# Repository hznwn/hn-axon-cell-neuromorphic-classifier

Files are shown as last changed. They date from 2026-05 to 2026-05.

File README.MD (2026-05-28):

# HN Axon Cell Neuromorphic Classifier

Discrete hardware implementation of the HN Axon Cell, a biologically inspired integrate-and-fire neuron for real-time light-direction classification using a 3×3 LDR sensor array, current mirrors, LTspice simulations, Arduino code, CAD models, and experimental data.

---
## Thesis Poster
<p align="center">
  <a href="media/HN_PRINT_A0.jpg">
    
  </a>
</p>

## Overview

This repository contains all source files, simulation models, experimental data, CAD designs, supplementary materials, and documentation associated with the bachelor's thesis:

**Implementation and Characterisation of a Discrete Neuromorphic Hardware System for Real-Time Light-Direction Classification**

The project investigates how core principles of biological neurons can be implemented using discrete electronic components. The resulting system, referred to as the **HN Axon Cell (HNAC)**, performs temporal integration, threshold detection, spike generation, and membrane reset to produce spike-frequency encoded outputs.

Nine HN Axon Cells were integrated with a curved 3×3 array of light-dependent resistors (LDRs) and an Arduino Uno R4 WiFi to create a complete neuromorphic system capable of real-time light-direction classification.

The prototype includes:

- 9 discrete integrate-and-fire neurons
- 9 light-dependent resistors (LDRs) arranged in a 3×3 sensor array
- CD4051B analogue multiplexer
- Arduino Uno R4 WiFi
- Automatic self-calibration and supervised template learning
- Real-time direction classification
- USB-C power consumption below 1 W

---

## Key Features

- Discrete implementation of an integrate-and-fire neuron
- Current mirror-based input stage
- Spike-frequency encoding of analogue sensor signals
- Real-time classification of light direction using a 3×3 LDR array
- Arduino-based template matching and LED matrix visualization
- LTspice simulation models
- Oscilloscope screenshots and experimental data
- 3D-printable sensor enclosure
- Full thesis documentation and supplementary materials

---

## Biological Inspiration

The HN Axon Cell is based on the leaky integrate-and-fire (LIF) neuron model.

| Biological Concept | Hardware Implementation |
|---|---|
| Membrane | Capacitor |
| Synaptic input current | PMOS current mirror |
| Threshold detection | SN74AHC14 Schmitt trigger |
| Spike and reset | BS170 MOSFET |
| Refractory shaping | Optional feedback capacitor |

---

## Repository Structure

```text
hn-axon-cell-neuromorphic-classifier/
├── arduino/
│   └── hn_axon_cell_classifier.ino
├── ltspice/
│   ├── preliminary_architectures/
│   ├── architecture_1/
│   └── hn_axon_cell/
├── cad/
│   └── ldr_sensor_array_3x3_curved.f3d
├── data/
│   ├── raw_measurements/
│   ├── calibration_templates/
│   ├── processed_results/
│   └── FINALRESULTS.csv
├── figures/
│   ├── oscilloscope/
│   ├── circuit_photos/
│   └── classification_demo/
├── docs/
│   ├── laboratory_notes/
│   │   └── HN_Axon_Cell_Laboratory_Development_Notes.pdf
│   ├── supplementary_material/
│   └── media/
├── thesis/
│   └── Thesis.pdf
├── LICENSE
└── README.md

⸻

Hardware Components
Neuron Circuit
	•	SN74AHC14 Schmitt trigger inverter
	•	BS170 NMOS transistor
	•	BS250 PMOS transistors
	•	Capacitors and resistors
	•	Light-dependent resistors (LDRs)
System Components
	•	Arduino Uno R4 WiFi
	•	CD4051B analogue multiplexer
	•	3×3 curved LDR sensor array
	•	USB 5 V power supply

⸻

Experimental Results
The HN Axon Cell exhibited:
	•	Stable and repeatable integrate-and-fire oscillations
	•	Firing frequency inversely proportional to membrane capacitance
	•	Stable threshold voltages across parameter sweeps
	•	Successful conversion of light intensity into spike frequency
	•	Reliable real-time classification of flashlight position
The completed system consistently identified the illuminated sensor position and displayed the detected direction on the Arduino LED matrix.

⸻

Supplementary Materials

The repository includes extensive supplementary material documenting the complete system and experimental results.
Supplementary Videos
Supplementary_Video_S1_Complete_System_Startup_Self_Training_and_Real_Time_3x3_Neuromorphic_Classification.MOV

Complete end-to-end demonstration showing:
	•	Program startup
	•	Ambient baseline calibration
	•	Self-training on all nine sensor positions
	•	Transition to live mode
	•	Real-time direction classification
Supplementary_Video_S4_Random_Order_3x3_Neuromorphic_Classification_Accuracy_Demonstration.MOV
Demonstrates classification of all nine sensor positions in random order. All positions were classified correctly during the recorded test.

⸻

Representative Neuron Oscilloscope Captures:
Oscilloscope_20260513_004451_Neuron7_IntegrateAndFire_Covered_LDR_Input_USB_C_Powered_5V.jpeg
Neuron 7 response with the corresponding LDR covered (minimal illumination).
Oscilloscope_20260513_004514_Neuron7_IntegrateAndFire_Ambient_Light_LDR_Input_USB_C_Powered_5V.jpeg
Neuron 7 response under ambient room lighting.
Oscilloscope_20260513_004541_Neuron7_IntegrateAndFire_Direct_Flashlight_LDR_Input_USB_C_Powered_5V.jpeg
Neuron 7 response under direct flashlight illumination.
These three captures demonstrate spike-frequency encoding, where the firing rate increases with increasing light intensity.

⸻

System Figures:
3x3_LDR_Sensor_Array_and_Neuromorphic_Neuron_Mapping.png
Physical layout and channel mapping of the 3×3 LDR sensor array.
Self_Training_3x3_Neuromorphic_Classification_System_Idle_Four_Corner_LEDs_USB_C_Powered_5V.png
Idle state of the classifier when no significant light stimulus is detected.
Self_Training_3x3_Neuromorphic_Classification_System_Active_Direction_Detection_USB_C_Powered_5V.png
Example of active real-time direction classification.
System_Power_Measurement_5p158V_0p154A_0p789W_USB_C_Powered.png
USB power measurement of the complete prototype.

⸻

Hardware Photographs:
	•	Neuron1-4.HEIC
Photograph of neurons 1 through 4.
	•	Neuron1-4_with_3dprint_plus_LDRs3x3.HEIC
Neurons 1 through 4 together with the 3D-printed sensor array.
	•	Neuron4_close_up.HEIC
Close-up photograph of a representative neuron.
	•	Neuron5-9_plus_meter_plus_arduino_plus_multiplexer.HEIC
Neurons 5 through 9 together with the Arduino, multiplexer, and power meter.
	•	Neuron5-9_plus_meter_plus_arduino_plus_multiplexer_plus_back_3x3LDR_3dprint.HEIC
Comprehensive overview of the complete hardware prototype.
	•	Neuron7-9.HEIC
Photograph of neurons 7 through 9.

⸻

Data Files:
FINALRESULTS.csv
Final validated dataset collected on May 13, 2026.
Contains sensor readings and classification outputs from the completed self-training 3×3 neuromorphic classification system after all hardware and software optimizations were finalized.

⸻

Power Consumption:
Measured using a KWS-2302C USB power meter.
Parameter
Value
Voltage
5.158 V
Current
0.154 A
Power
0.789 W
Estimated meter overhead: approximately 0.01 to 0.05 W.
Estimated actual system power consumption: approximately 0.74 to 0.78 W.
These measurements confirm that the complete neuromorphic classification system operates well below 1 W.

⸻

System Notes
	•	The system performs self-calibration and retraining at every startup.
	•	The classifier adapts to different ambient lighting conditions.
	•	Sensors N1 to N8 are read through the CD4051B analogue multiplexer.
	•	Sensor N9 is connected directly to Arduino analogue input A1.
	•	The system is powered entirely from a standard 5 V USB-C connection.

⸻

Thesis Abstract
This work demonstrates how biologically inspired neural computation can be implemented using discrete electronic components. The developed HN Axon Cell reproduces the core behaviour of a spiking neuron and forms the basis of a nine-neuron neuromorphic hardware system capable of real-time light-direction classification.
The project bridges theoretical neuroscience, analogue circuit design, simulation, embedded programming, and experimental validation.

⸻

Software and Tools Used
	•	LTspice
	•	Arduino IDE
	•	Microsoft Word
	•	Fusion 360
	•	Rigol DS1202 Oscilloscope

⸻

License
This project is licensed under the MIT License. See the LICENSE file for details.

⸻

Author
Haze Newman
Bachelor’s Thesis in Electrical Engineering
Uppsala University
2026

⸻

Citation
If you use this work in research or development, please cite the associated bachelor’s thesis and reference this repository.

⸻

Contact
For questions, collaboration, or future research opportunities, please open an issue on GitHub.

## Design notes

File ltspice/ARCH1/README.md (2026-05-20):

ARCH1_SIMULATION_ONLY
=====================

Description
-----------
This LTspice file contains a functional simulation of the preliminary voltage-driven integrate-and-fire neuron developed during the early stages of this thesis project.

The circuit served as the first proof-of-concept implementation and was used to verify that a discrete electronic circuit could reproduce the essential behaviour of a biological spiking neuron.

Important Note
--------------
This simulation file is intended for functional validation only and does NOT necessarily represent the exact component values used in the final experimental implementation.

Several component values were adjusted to obtain stable and visually clear integrate-and-fire behaviour in LTspice. The simulation should therefore be interpreted as a conceptual demonstration rather than an exact replication of the physical prototype.

The corresponding file ARCH1_SCHEMATIC_ONLY contains a clean schematic of the architecture and includes both the fixed resistive input and the optional LDR-based voltage divider used in early experiments.

Purpose of the Simulation
-------------------------
The simulation was created to verify the following sequence of operations:

1. The membrane capacitor is charged through a resistive input stage.
2. The membrane voltage (Vmem) increases over time.
3. A Schmitt trigger detects when the threshold is reached.
4. A second inverter restores the correct signal polarity.
5. An NMOS transistor rapidly discharges the membrane capacitor.
6. The cycle repeats, producing integrate-and-fire oscillations.

This behaviour reproduces the fundamental principles of the leaky integrate-and-fire neuron model.

Architecture Overview
---------------------
The preliminary architecture consists of:

- Input resistor or LDR-based voltage divider
- Membrane capacitor (Cmem)
- Two SN74AHC14 Schmitt-trigger inverter stages
- BS170 NMOS reset transistor
- Supporting resistors

The same threshold and reset subsystem was later reused in the HN Axon Cell, where the resistive input stage was replaced by a PMOS current mirror.

Simulation Files
----------------
ARCH1_SCHEMATIC_ONLY.asc
    Clean schematic of the preliminary voltage-driven architecture.

ARCH1_SIMULATION_ONLY.asc
    Functional LTspice simulation used to demonstrate integrate-and-fire behaviour.

README.txt
    This document.

Models Used
-----------
- SN74AHC14.cir
- BS170 model defined directly in the schematic

Interpretation of Results
-------------------------
The most important output is the membrane voltage Vmem.

A successful simulation produces a sawtooth waveform showing:

- gradual charging of the membrane capacitor,
- threshold crossing,
- rapid reset,
- repeated oscillation.

The output of the Schmitt trigger stages appears as a digital spike train.

Relationship to the HN Axon Cell
--------------------------------
This preliminary architecture was used to validate the fundamental integrate-and-fire mechanism and to perform early experiments with push-button and photoresistor inputs.

After successful testing, the resistive input stage was replaced by a PMOS current mirror, resulting in the HN Axon Cell (HNAC), the final neuron architecture presented in this thesis.

Author
------
Haze Newman
Bachelor's Thesis in Electrical Engineering
Uppsala University
2026

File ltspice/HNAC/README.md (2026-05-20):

HNAC_SIMULATION_ONLY
====================

Description
-----------
This LTspice file contains a functional simulation of the HN Axon Cell (HNAC), a discrete-component neuromorphic neuron developed as part of a Bachelor's thesis in Electrical Engineering at Uppsala University.

The purpose of this simulation is to demonstrate the fundamental integrate-and-fire behaviour of the architecture in a clear and reproducible manner.

Important Note
--------------
This simulation file does NOT represent the exact component values used in the final breadboard implementation.

Several component values were intentionally adjusted to obtain stable and visually clear integrate-and-fire behaviour in LTspice. These modifications were made solely for simulation and demonstration purposes.

The separate file HNAC_SCHEMATIC_ONLY contains the circuit topology and nominal component values corresponding more closely to the physical implementation.

Purpose of the Simulation
-------------------------
The simulation was created to verify the following sequence of operations:

1. Input current charges the membrane capacitor (Cmem).
2. The membrane voltage (Vmem) increases over time.
3. A Schmitt trigger detects when the threshold is reached.
4. A second inverter restores the correct signal polarity.
5. An NMOS transistor rapidly discharges the membrane capacitor.
6. The cycle repeats, producing integrate-and-fire oscillations.

This behaviour reproduces the core computational principles of the leaky integrate-and-fire neuron model.

Simulation-Specific Modifications
---------------------------------
The following adjustments may differ from the final hardware implementation:

- Current mirror bias resistors were tuned to provide sufficient charging current.
- Additional resistors were modified to improve convergence and stability.
- Simulation models were used for:
  - BS250 PMOS transistors
  - BS170 NMOS transistor
  - SN74AHC14 Schmitt trigger inverter
- Initial conditions were specified to ensure proper startup.
- Transient analysis settings were selected to clearly display repetitive firing.

These changes were made to validate the architecture rather than to exactly replicate measured experimental values.

Files Included
--------------
HNAC_SIMULATION_ONLY.asc
    LTspice simulation file with adjusted values for functional validation.

HNAC_SCHEMATIC_ONLY.asc
    Clean schematic showing the architecture and nominal hardware values.

README.txt
    This document.

Models Used
-----------
- BS250.philips.lib
- SN74AHC14.cir
- BS170 model defined directly in the schematic

Interpretation of Results
-------------------------
The most important output is the membrane voltage Vmem.

A successful simulation produces a sawtooth waveform:
- gradual charging of the membrane capacitor,
- threshold crossing,
- rapid reset,
- repeated oscillation.

This confirms correct integrate-and-fire behaviour.

Thesis Context
--------------
This simulation supports the statement that the HN Axon Cell architecture is capable of reproducing biologically inspired spiking neuron dynamics using discrete commercially available electronic components.

The simulation should be interpreted as a functional validation of the design rather than an exact digital twin of the physical breadboard implementation.

Author
------
Haze
Bachelor's Thesis in Electrical Engineering
Uppsala University
2026

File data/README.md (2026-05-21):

README.txt
==========

3×3 Neuromorphic Light-Direction Classification Data and Analysis
=================================================================

This folder contains the raw Arduino IDE serial export and the Python script
used to generate the supplementary classification figures and tables presented
in the appendix of the thesis.

Raw Data File
-------------

Final_Validated_3x3_Neuromorphic_Classification_Results_2026_05_13_arduinoide_export.csv

This file is the original serial data export from the Arduino IDE. It contains:

- Timestamp (time_ms)
- Raw sensor readings (N1–N9)
- Activity metric
- Raw classifier output (rawWinner)
- Stable classifier output (stableWinner)
- Similarity score

The file includes both calibration messages and live classification data.

Python Analysis Script
----------------------

confusion.py

Running this script automatically:

1. Extracts the tabular data from the Arduino IDE export.
2. Detects classification segments using the stable classifier output.
3. Assigns a trueClass label to each segment.
4. Computes classification accuracy.
5. Generates confusion matrices, plots, and summary tables.

Generated Output Files
----------------------

The following files are created in:

generated_classification_figures/

CSV Files
---------

generated_classification_figures/per_class_sample_counts.csv
generated_classification_figures/confusion_matrix_true_vs_predicted.csv
generated_classification_figures/accuracy_by_class.csv
generated_classification_figures/classification_data_with_trueClass.csv
generated_classification_figures/detected_trueclass_time_blocks.csv
generated_classification_figures/similarity_score_summary.csv

Image Files
-----------

generated_classification_figures/classification_stability_over_time.png
generated_classification_figures/confusion_matrix_true_vs_predicted.png
generated_classification_figures/similarity_score_distribution.png
generated_classification_figures/per_class_sample_counts.png
generated_classification_figures/accuracy_by_class.png

Summary of Results
------------------

The analysis produced the following key results:

- 392 valid classification samples
- 100.00% overall classification accuracy
- 100.00% accuracy for all nine classes (N1–N9)
- Zero misclassifications
- Perfect diagonal confusion matrix

These results confirm that the neuromorphic light-direction classification
system operated reliably under the controlled experimental conditions used
in this study.

Requirements
------------

The Python script requires the following packages:

- pandas
- numpy
- matplotlib

Install them using:

pip install pandas numpy matplotlib

Usage
-----

Place the following files in the same directory:

- confusion.py
- Final_Validated_3x3_Neuromorphic_Classification_Results_2026_05_13_arduinoide_export.csv

Run:

python confusion.py

A new folder named generated_classification_figures will be created containing
all generated figures and summary tables.

Author
------

Haza Newman
Uppsala University
Degree Project in Electrical Engineering
2026

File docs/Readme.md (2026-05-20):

Laboratory Development Notes
Supplementary laboratory notes documenting the phases of the project, including circuit development, testing, and experimental observations, are included. These notes are provided in their original handwritten form to preserve the chronological and transparent record of the experimental development of the work:

https://web.goodnotes.com/s/xlsEbIUI6iuXck66CYKlLw

If the Goodnotes link no longer works, the file can be also found via this url (requires UU access):

https://uppsalauniversitet.sharepoint.com/sites/ExperimentDataStorage/Shared%20Documents/Forms/AllItems.aspx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

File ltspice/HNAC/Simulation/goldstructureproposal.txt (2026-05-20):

Intro

The song opens with distant cinematic impacts, reversed cymbals, dark sub drones, and ambient clean guitar swells. Haunting choir pads and soft strings slowly build tension.

Build

Spiccato strings and pizzicato patterns begin to pulse underneath the atmosphere. Timpani rolls and low brass swell as palm-muted Drop A guitars start creeping in.

Verse 1

Crushing Drop A guitars and tight double-kick drums drive the song forward. Symphonic strings mirror the riff while dark synth textures and layered vocals create a massive wall of sound.

Chorus

The energy opens up into a soaring vocal hook supported by harmonized lead guitars, full string ensemble, choir, and emotional chord changes. This is the main melodic centerpiece of the song.

Verse 2

The heavy riff returns with syncopated chugs, aggressive drums, and sharper orchestral accents. Additional vocal layers increase the intensity.

Chorus

The main hook returns with bigger harmonies, denser orchestration, and more emotional weight.

Pre-Breakdown

The arrangement strips back and builds tension with tom fills, rising choirs, tremolo strings, and reversed impacts.

Final Brutal Breakdown

Half-time drums and devastating Drop A guitar accents hit alongside china cymbals, machine-gun kicks, orchestral stabs, and crushing low brass.

Post-Breakdown Resolution

The violence gives way to an epic melodic section where vocals and lead guitars intertwine over soaring strings and powerful half-time drums.

Final Chorus

The largest and most emotional statement of the song. Full choir, brass, dual lead guitars, and layered vocals push the main hook to its peak.

Outro

The arrangement gradually fades with clean guitar echoes, distant choir, sustained strings, and a dark sub drone dissolving into silence.

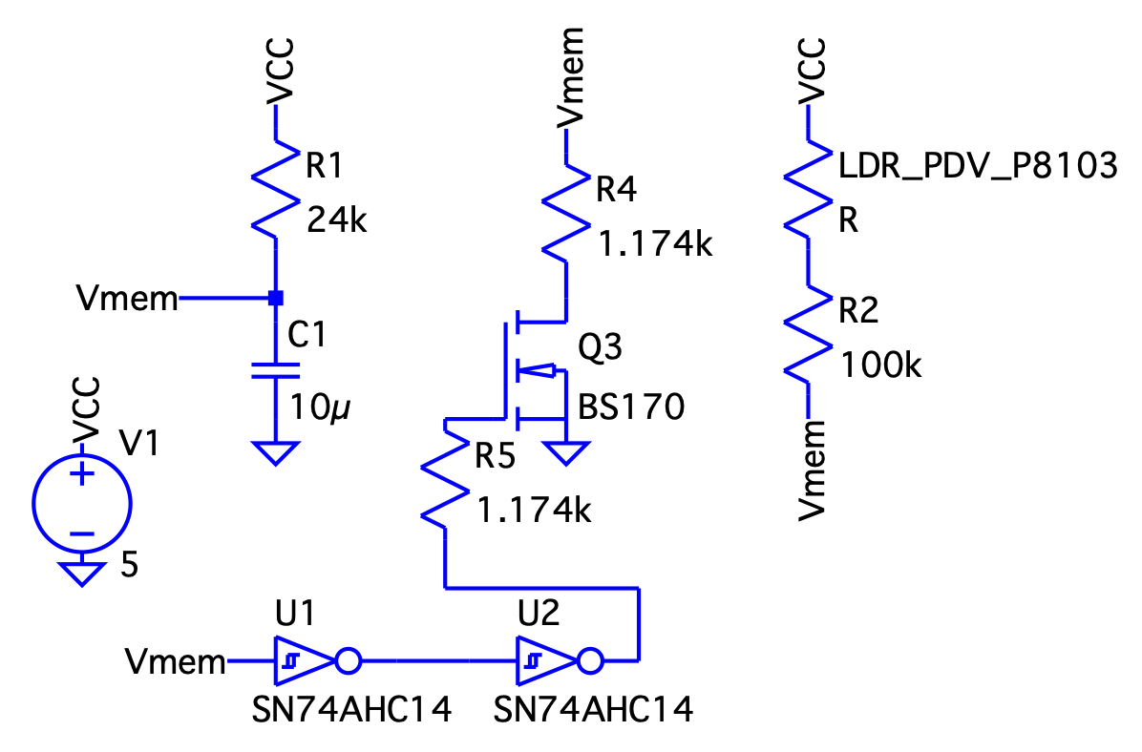
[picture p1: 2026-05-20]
figures/schematics/ARCH1/ARCH1_SCHEMATIC.png

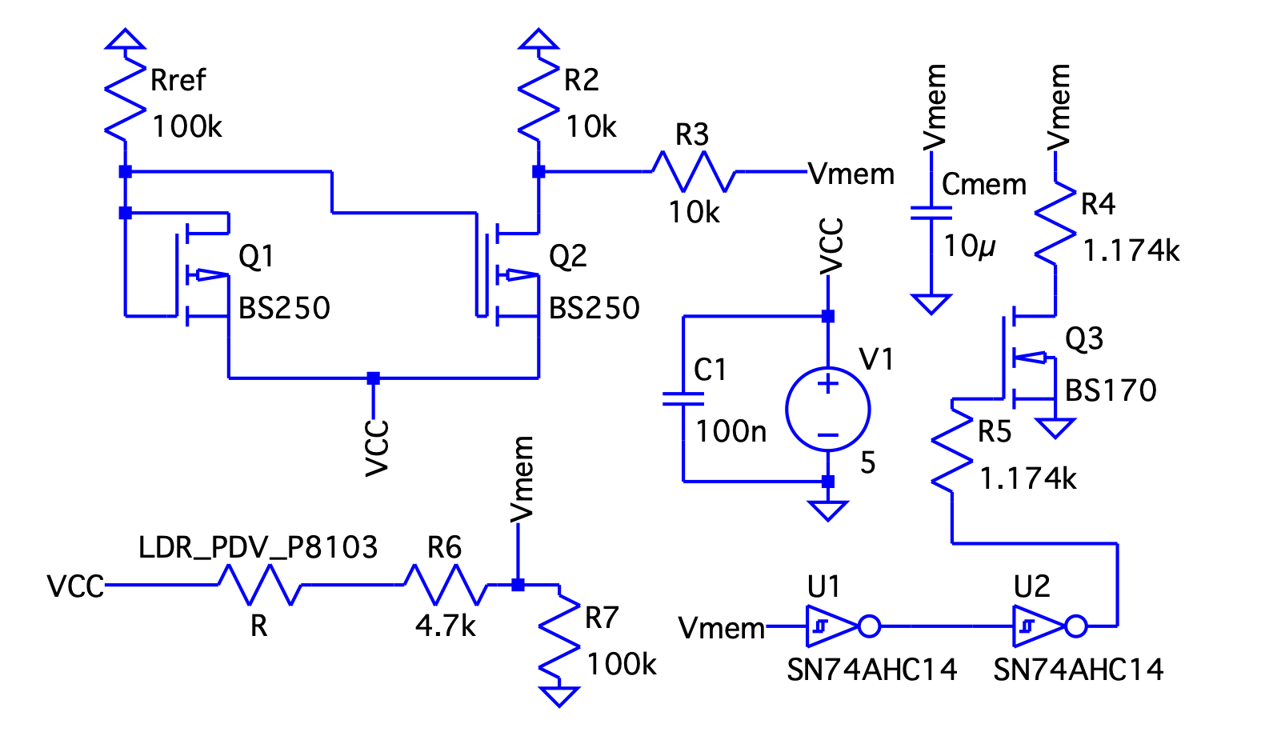
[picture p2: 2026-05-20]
figures/schematics/HNAC/hnaxoncell_SCHEMATIC.png

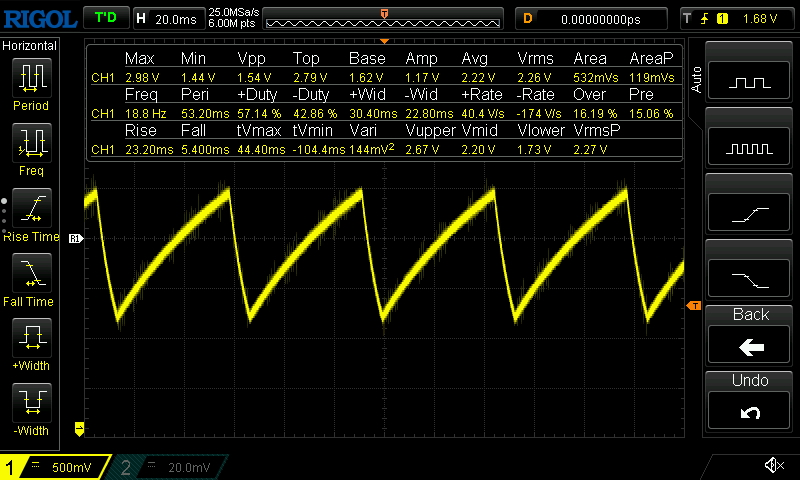
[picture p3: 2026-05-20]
figures/oscilloscopefigures/Oscilloscope_20260513_004514_Neuron7_IntegrateAndFire_Ambient_Light_LDR_Input_USB_C_Powered_5V.jpeg

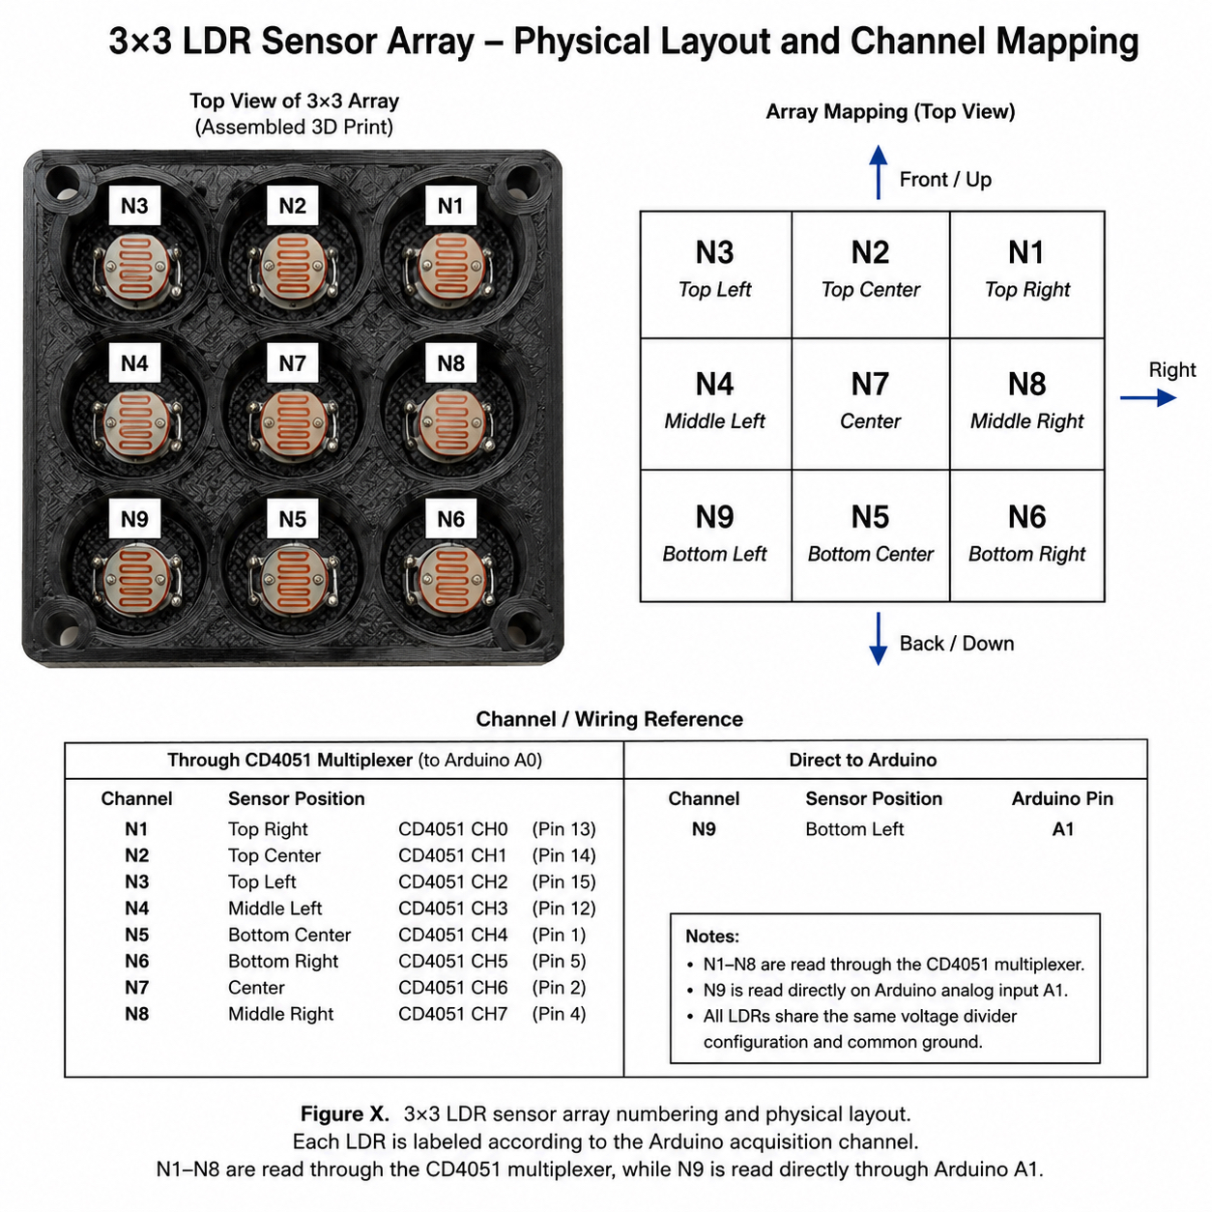
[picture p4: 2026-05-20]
figures/ldr_sensor_mapping/3x3_LDR_Sensor_Array_and_Neuromorphic_Neuron_Mapping.jpeg

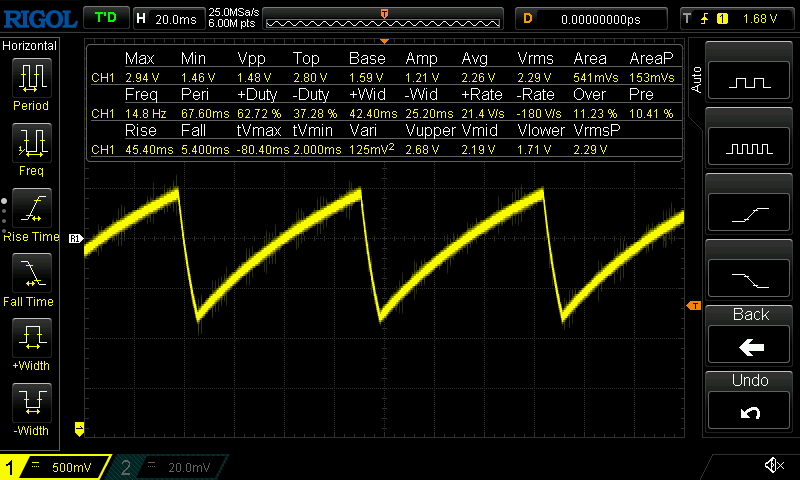
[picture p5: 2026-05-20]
figures/oscilloscopefigures/Oscilloscope_20260513_004451_Neuron7_IntegrateAndFire_Covered_LDR_Input_USB_C_Powered_5V.jpeg

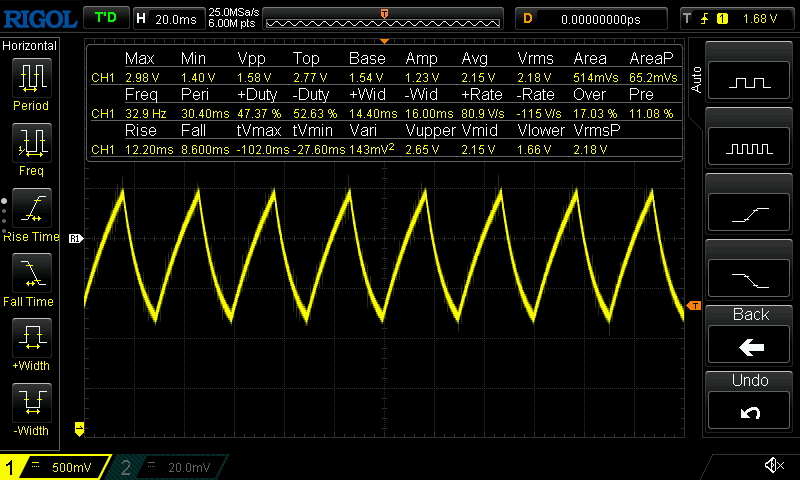
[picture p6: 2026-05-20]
figures/oscilloscopefigures/Oscilloscope_20260513_004541_Neuron7_IntegrateAndFire_Direct_Flashlight_LDR_Input_USB_C_Powered_5V.png.jpeg

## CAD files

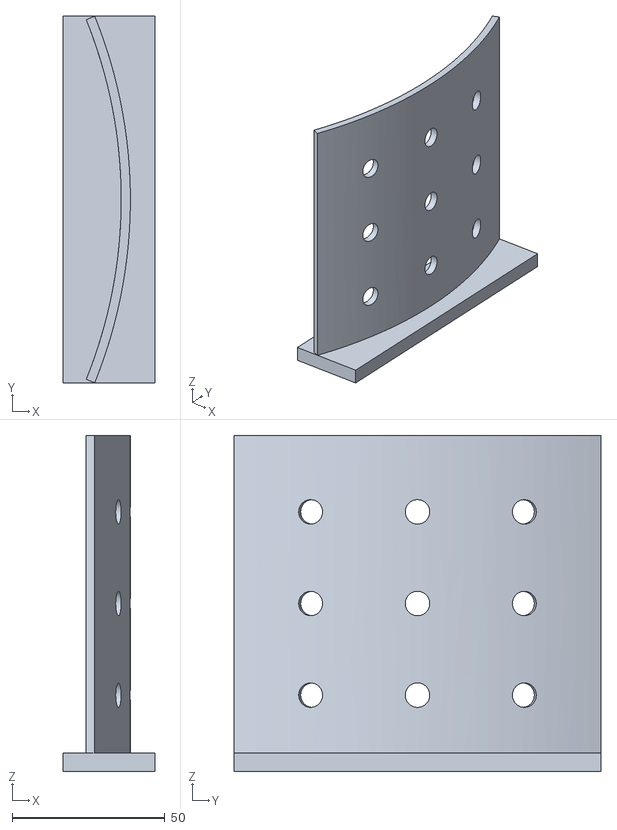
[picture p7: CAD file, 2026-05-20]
cad/ldr_sensor_array_3x3_curved.stl
30.0 x 120.0 x 110.0

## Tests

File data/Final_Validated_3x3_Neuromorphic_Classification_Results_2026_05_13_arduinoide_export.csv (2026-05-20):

=== 3x3 LDR DIRECTION CLASSIFIER ===
Step 1: Keep flashlight away.
Calibrating ambient baseline...
Baseline: N1=589.61 N2=567.43 N3=561.84 N4=553.72 N5=568.90 N6=553.77 N7=562.58 N8=546.07 N9=555.45
Step 2: Template calibration begins.
Move flashlight to the dot shown on the LED matrix.
You will get a 5 second countdown.
Then 10 seconds of data are recorded.
Point flashlight at N3_UP_LEFT.
Recording starts in 5...
Recording starts in 4...
Recording starts in 3...
Recording starts in 2...
Recording starts in 1...
Recording now. Hold flashlight steady.
Learned template for N3_UP_LEFT
Point flashlight at N2_UP.
Recording starts in 5...
Recording starts in 4...
Recording starts in 3...
Recording starts in 2...
Recording starts in 1...
Recording now. Hold flashlight steady.
Learned template for N2_UP
Point flashlight at N1_UP_RIGHT.
Recording starts in 5...
Recording starts in 4...
Recording starts in 3...
Recording starts in 2...
Recording starts in 1...
Recording now. Hold flashlight steady.
Learned template for N1_UP_RIGHT
Point flashlight at N4_LEFT.
Recording starts in 5...
Recording starts in 4...
Recording starts in 3...
Recording starts in 2...
Recording starts in 1...
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

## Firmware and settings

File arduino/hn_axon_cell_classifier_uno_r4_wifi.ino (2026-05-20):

/*
  3x3 LDR LIGHT DIRECTION CLASSIFIER

  Hardware:
  - Arduino UNO R4 WiFi
  - Built-in 12x8 LED matrix
  - 9 LDR sensors
  - CD4051B multiplexer for N1-N8
  - N9 directly connected to A1

  Physical layout:

        N3    N2    N1
        N4    N7    N8
        N9    N5    N6

  Main fix in this version:
  - N9 scaling is NOT applied during baseline calibration.
  - N9 scaling is applied only after baselineReady = true.
*/

#include "Arduino_LED_Matrix.h"
#include <math.h>

ArduinoLEDMatrix matrix;

// Pins
const int S0 = 2;
const int S1 = 3;
const int S2 = 4;

const int MUX_SIG = A0;
const int SENSOR9 = A1;

// Settings
const int NUM_SENSORS = 9;

const int BASELINE_SAMPLES = 100;
const int TEMPLATE_SAMPLES = 200;
const int TEMPLATE_DELAY = 50;

const int LIVE_DELAY = 90;

const float ACTIVITY_THRESHOLD = 50.0;
const float N9_SCALE = 0.50;

const int HISTORY_LEN = 17;

// Data
int values[NUM_SENSORS];

float baseline[NUM_SENSORS];
float livePattern[NUM_SENSORS];
float templates[NUM_SENSORS][NUM_SENSORS];

int winnerHistory[HISTORY_LEN];
int historyIndex = 0;

uint8_t frame[8][12];

// Important: prevents N9 compensation from corrupting baseline.
bool baselineReady = false;

// Internal index mapping:
// N1=0, N2=1, N3=2, N4=3, N5=4, N6=5, N7=6, N8=7, N9=8

int calibrationOrder[9] = {
  2, 1, 0,
  3, 6, 7,
  8, 4, 5
};

const char* names[9] = {
  "N1_UP_RIGHT",
  "N2_UP",
  "N3_UP_LEFT",
  "N4_LEFT",
  "N5_DOWN",
  "N6_DOWN_RIGHT",
  "N7_CENTER",
  "N8_RIGHT",
  "N9_DOWN_LEFT"
};

void setup() {
  Serial.begin(115200);

  pinMode(S0, OUTPUT);
  pinMode(S1, OUTPUT);
  pinMode(S2, OUTPUT);

  matrix.begin();

  resetHistoryToCenter();
  drawIdle();

  delay(1500);

  Serial.println("=== 3x3 LDR DIRECTION CLASSIFIER ===");
  Serial.println("Step 1: Keep flashlight away.");
  Serial.println("Calibrating ambient baseline...");

  calibrateBaseline();

  Serial.println();
  Serial.println("Step 2: Template calibration begins.");
  Serial.println("Move flashlight to the dot shown on the LED matrix.");
  Serial.println("You will get a 5 second countdown.");
  Serial.println("Then 10 seconds of data are recorded.");

  delay(2000);

  calibrateTemplates();

  Serial.println();
  Serial.println("Calibration complete.");
  Serial.println("Live classification started.");
  Serial.println("time_ms,N1,N2,N3,N4,N5,N6,N7,N8,N9,activity,rawWinner,stableWinner,score");

  drawIdle();
}

void selectChannel(int ch) {
  digitalWrite(S0, ch & 0x01);
  digitalWrite(S1, (ch >> 1) & 0x01);
  digitalWrite(S2, (ch >> 2) & 0x01);

  delayMicroseconds(100);
}

void readSensors() {
  // Read N1-N8 through CD4051.
  for (int ch = 0; ch < 8; ch++) {
    selectChannel(ch);
    values[ch] = analogRead(MUX_SIG);
  }

  // Read N9 directly.
  int rawN9 = analogRead(SENSOR9);

  /*
    Critical fix:

    During baseline calibration, baseline[8] is not valid yet.
    So we must read raw N9 without compensation.

    After baseline is calibrated, we scale only the delta:

      corrected_N9 = baseline_N9 + N9_SCALE * (raw_N9 - baseline_N9)
  */

  if (!baselineReady) {
    values[8] = rawN9;
  } else {
    values[8] = baseline[8] + N9_SCALE * (rawN9 - baseline[8]);
  }
}

void averageSensors(float out[NUM_SENSORS], int samples, int delayMs) {
  float sums[NUM_SENSORS] = {0};

  for (int k = 0; k < samples; k++) {
    readSensors();

    for (int i = 0; i < NUM_SENSORS; i++) {
      sums[i] += values[i];
    }

    delay(delayMs);
  }

  for (int i = 0; i < NUM_SENSORS; i++) {
    out[i] = sums[i] / samples;
  }
}

void calibrateBaseline() {
  baselineReady = false;

  averageSensors(baseline, BASELINE_SAMPLES, 30);

  baselineReady = true;

  Serial.print("Baseline: ");

  for (int i = 0; i < NUM_SENSORS; i++) {
    Serial.print("N");
    Serial.print(i + 1);
    Serial.print("=");
    Serial.print(baseline[i], 2);
    Serial.print(" ");
  }

  Serial.println();
}

void countdown5() {
  for (int n = 5; n >= 1; n--) {
    Serial.print("Recording starts in ");
    Serial.print(n);
    Serial.println("...");
    delay(1000);
  }

  Serial.println("Recording now. Hold flashlight steady.");
}

void calibrateTemplates() {
  for (int step = 0; step < NUM_SENSORS; step++) {
    int sensorIndex = calibrationOrder[step];

    drawDotForSensor(sensorIndex);

    Serial.println();
    Serial.print("Point flashlight at ");
    Serial.print(names[sensorIndex]);
    Serial.println(".");

    countdown5();

    float avg[NUM_SENSORS];
    averageSensors(avg, TEMPLATE_SAMPLES, TEMPLATE_DELAY);

    for (int i = 0; i < NUM_SENSORS; i++) {
      templates[sensorIndex][i] = avg[i] - baseline[i];
    }

    removeCommonMode(templates[sensorIndex]);
    normalizePattern(templates[sensorIndex]);

    Serial.print("Learned template for ");
    Serial.println(names[sensorIndex]);

    delay(700);
  }
}

void removeCommonMode(float pattern[NUM_SENSORS]) {
  float mean = 0;

  for (int i = 0; i < NUM_SENSORS; i++) {
    mean += pattern[i];
  }

  mean /= NUM_SENSORS;

  for (int i = 0; i < NUM_SENSORS; i++) {
    pattern[i] -= mean;
  }
}

void normalizePattern(float pattern[NUM_SENSORS]) {
  float norm = 0;

  for (int i = 0; i < NUM_SENSORS; i++) {
    norm += pattern[i] * pattern[i];
  }

  norm = sqrt(norm);

  if (norm < 0.001) {
    return;
  }

  for (int i = 0; i < NUM_SENSORS; i++) {
    pattern[i] /= norm;
  }
}

void buildLivePattern() {
  readSensors();

  for (int i = 0; i < NUM_SENSORS; i++) {
    livePattern[i] = values[i] - baseline[i];
  }

  removeCommonMode(livePattern);
  normalizePattern(livePattern);
}

float computeActivityFromRawDelta() {
  float sumAbs = 0;

  for (int i = 0; i < NUM_SENSORS; i++) {
    sumAbs += fabs(values[i] - baseline[i]);
  }

  return sumAbs / NUM_SENSORS;
}

float similarity(float a[NUM_SENSORS], float b[NUM_SENSORS]) {
  float dot = 0;

  for (int i = 0; i < NUM_SENSORS; i++) {
    dot += a[i] * b[i];
  }

  return dot;
}

int classifyLive(float &bestScore) {
  buildLivePattern();

  int bestIndex = 0;
  bestScore = -999;

  for (int k = 0; k < NUM_SENSORS; k++) {
    float s = similarity(livePattern, templates[k]);

    if (s > bestScore) {
      bestScore = s;
      bestIndex = k;
    }
  }

  return bestIndex;
}

void resetHistoryToCenter() {
  for (int i = 0; i < HISTORY_LEN; i++) {
    winnerHistory[i] = 6; // N7 center
  }

  historyIndex = 0;
}

int getStableWinner(int newWinner) {
  winnerHistory[historyIndex] = newWinner;
  historyIndex = (historyIndex + 1) % HISTORY_LEN;

  int counts[NUM_SENSORS] = {0};

  for (int i = 0; i < HISTORY_LEN; i++) {
    int w = winnerHistory[i];

    if (w >= 0 && w < NUM_SENSORS) {
      counts[w]++;
    }
  }

  int best = 0;

  for (int i = 1; i < NUM_SENSORS; i++) {
    if (counts[i] > counts[best]) {
      best = i;
    }
  }

  return best;
}

void clearFrame() {
  for (int r = 0; r < 8; r++) {
    for (int c = 0; c < 12; c++) {
      frame[r][c] = 0;
    }
  }
}

void setPixelMapped(int r, int c) {
  int rr = 7 - r;
  int cc = 11 - c;

  if (rr >= 0 && rr < 8 && cc >= 0 && cc < 12) {
    frame[rr][cc] = 1;
  }
}

void drawDotForSensor(int index) {
  clearFrame();

  int row = 3;
  int col = 5;

  // Physical display layout:
  //
  // N3  N2  N1
  // N4  N7  N8
  // N9  N5  N6

  if (index == 2) { row = 0; col = 1; }  // N3
  if (index == 1) { row = 0; col = 5; }  // N2
  if (index == 0) { row = 0; col = 9; }  // N1

  if (index == 3) { row = 3; col = 1; }  // N4
  if (index == 6) { row = 3; col = 5; }  // N7
  if (index == 7) { row = 3; col = 9; }  // N8

  if (index == 8) { row = 6; col = 1; }  // N9
  if (index == 4) { row = 6; col = 5; }  // N5
  if (index == 5) { row = 6; col = 9; }  // N6

  setPixelMapped(row, col);
  setPixelMapped(row, col + 1);
  setPixelMapped(row + 1, col);
  setPixelMapped(row + 1, col + 1);

  matrix.renderBitmap(frame, 8, 12);
}

void drawIdle() {
  clearFrame();

  // Four single corner LEDs = idle / no confident light direction detected

  setPixelMapped(0, 0);    // top left
  setPixelMapped(0, 11);   // top right
  setPixelMapped(7, 0);    // bottom left
  setPixelMapped(7, 11);   // bottom right

  matrix.renderBitmap(frame, 8, 12);
}

void loop() {
  float score;

  int rawWinner = classifyLive(score);

  float activity = computeActivityFromRawDelta();

  if (activity < ACTIVITY_THRESHOLD) {
    resetHistoryToCenter();
    drawIdle();

    Serial.print(millis());
    Serial.print(",");

    for (int i = 0; i < NUM_SENSORS; i++) {
      Serial.print(values[i]);
      Serial.print(",");
    }

    Serial.print(activity, 2);
    Serial.println(",NONE,NONE,0.000");

    delay(LIVE_DELAY);
    return;
  }

  int stableWinner = getStableWinner(rawWinner);

  drawDotForSensor(stableWinner);

  Serial.print(millis());
  Serial.print(",");

  for (int i = 0; i < NUM_SENSORS; i++) {
    Serial.print(values[i]);
    Serial.print(",");
  }

  Serial.print(activity, 2);
  Serial.print(",");

  Serial.print("N");
  Serial.print(rawWinner + 1);
  Serial.print(",");

  Serial.print("N");
  Serial.print(stableWinner + 1);
  Serial.print(",");

  Serial.println(score, 3);

  delay(LIVE_DELAY);
}
